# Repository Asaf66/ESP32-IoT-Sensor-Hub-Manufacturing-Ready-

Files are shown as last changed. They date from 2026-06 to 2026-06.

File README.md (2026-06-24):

# ESP32-C3 Multi-Sensor IoT & Data Logger
hardware system based on ESP32-C3 (RISC-V architecture) on a 4-layer PCB for noise immunity. 

The project includes sensors (environment, light, and sound), smart power and charging management (MCP73871), and a user interface.
The system supports local data storage via SD card and external flash memory via SPI connection, with Wi-Fi and BLE connectivity.

1) All-in-One Sensing Solution: Integrated temperature, humidity, light, and sound sensors, eliminating the need for multiple external modules.
2) Industrial-Grade Reliability: The 4-layer design ensures the device operates without interference in noisy industrial environments.
3) Seamless Power Integration: Built-in USB-C charging and battery management, meaning your product is portable and user-friendly from day one.
4) Rapid Manufacturing: Delivered with a full production package (Gerbers, BOM, Pick-and-Place), optimized to minimize assembly errors and part costs.

3D View
Sensores
User Interface
ESP32
Power
Front Back Layers
4 Layers

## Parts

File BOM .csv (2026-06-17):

Id | Designator | Footprint | Quantity | Designation | Supplier and ref
1 | R3,R4 | R_0805_2012Metric | 2 | 5K1
2 | LED2,LED5 | LEDC2012X120N | 2 | LTST-C170GKT
3 | R6 | R_0805_2012Metric | 1 | 20K
4 | C2,C8,C18,C14,C5,C21,C1,C10,C15,C13 | C_0805_2012Metric | 10 | 0.1u
5 | R12 | R_0805_2012Metric | 1 | 22K1
6 | C16 | C_0805_2012Metric | 1 | 0.1U
7 | LED4,LED6,LED1 | LEDC2012X120N | 3 | LTST-C170KRKT
8 | R5,R26,R28 | R_0805_2012Metric | 3 | 2K
9 | C22,C11,C19,C6 | C_0805_2012Metric | 4 | 1u
10 | LED3 | LEDC2012X120N | 1 | LTST-C170TBKT
11 | Q1 | TRANS_TEMT6000X01 | 1 | TEMT6000X01
12 | S2 | SW_USLPT2819DT2TR | 1 | RESET
13 | U6 | SOIC127P790X216-8N | 1 | W25Q32JVSSIQ
14 | R7,R14,R9,R8,R18,R10 | R_0805_2012Metric | 6 | 470
15 | R15,R22,R16,R20 | R_0805_2012Metric | 4 | 50
16 | U7 | SOT65P210X110-5N | 1 | MAX4466EXK
17 | R27,R29 | R_0805_2012Metric | 2 | 1M
18 | R24,R25 | R_0805_2012Metric | 2 | 4K7
19 | U5 | SOT-23-6 | 1 | USBLC6-2SC6
20 | TP3,TP5,TP4,TP2,TP1 | TestPoint_Pad_D1.0mm | 5 | TestPoint
21 | J4 | PinHeader_1x04_P2.54mm_Vertical | 1 | Conn_01x04_Pin
22 | U2 | PSON65P250X250X100-8N | 1 | BME280
23 | R23,R19,R33,R32,R34,R30,R2,R1 | R_0805_2012Metric | 8 | 10K
24 | J5 | PinHeader_1x05_P2.54mm_Vertical | 1 | Conn_01x05_Pin
25 | Q2,Q3 | SOT-23 | 2 | BC817
26 | U4 | SiliconLabs_QFN-20-1EP_3x3mm_P0.5mm_EP1.8x1.8mm | 1 | CP2102N-Axx-xQFN20
27 | F1 | FUSC3226X100N | 1 | 0ZCH0110AF2E
28 | S1 | SW_USLPT2819DT2TR | 1 | BOOT
29 | R11 | R_0805_2012Metric | 1 | 1K
30 | U3 | MODULE_ESP32-C3-WROOM-02-H4 | 1 | ESP32-C3-WROOM-02-H4
31 | U1 | QFN-20-1EP_4x4mm_P0.5mm_EP2.5x2.5mm | 1 | MCP73871-2CAI_ML
32 | C9 | T491A | 1 | 4.7u
33 | J2 | JST_B2B-PH-SM4-TB | 1 | B2B-PH-SM4-TB
34 | C17 | C_0805_2012Metric | 1 | 0.01U
35 | C20 | C_0805_2012Metric | 1 | 100p
36 | R13 | R_0805_2012Metric | 1 | 47K5
37 | C12,C3,C7,C4 | T491A | 4 | 10u
38 | MK1 | CUI_CMC-5042PF-AC | 1 | CMC-5042PF-AC
39 | R31 | R_0805_2012Metric | 1 | 100K
40 | J1 | BELFUSE_SS-52400-002 | 1 | SS-52400-002
41 | VR1 | VREG_LM1117MPX-3.3 | 1 | LM1117MPX-3.3
42 | J3 | AMPHENOL_GSD090012SEU | 1 | GSD090012SEU

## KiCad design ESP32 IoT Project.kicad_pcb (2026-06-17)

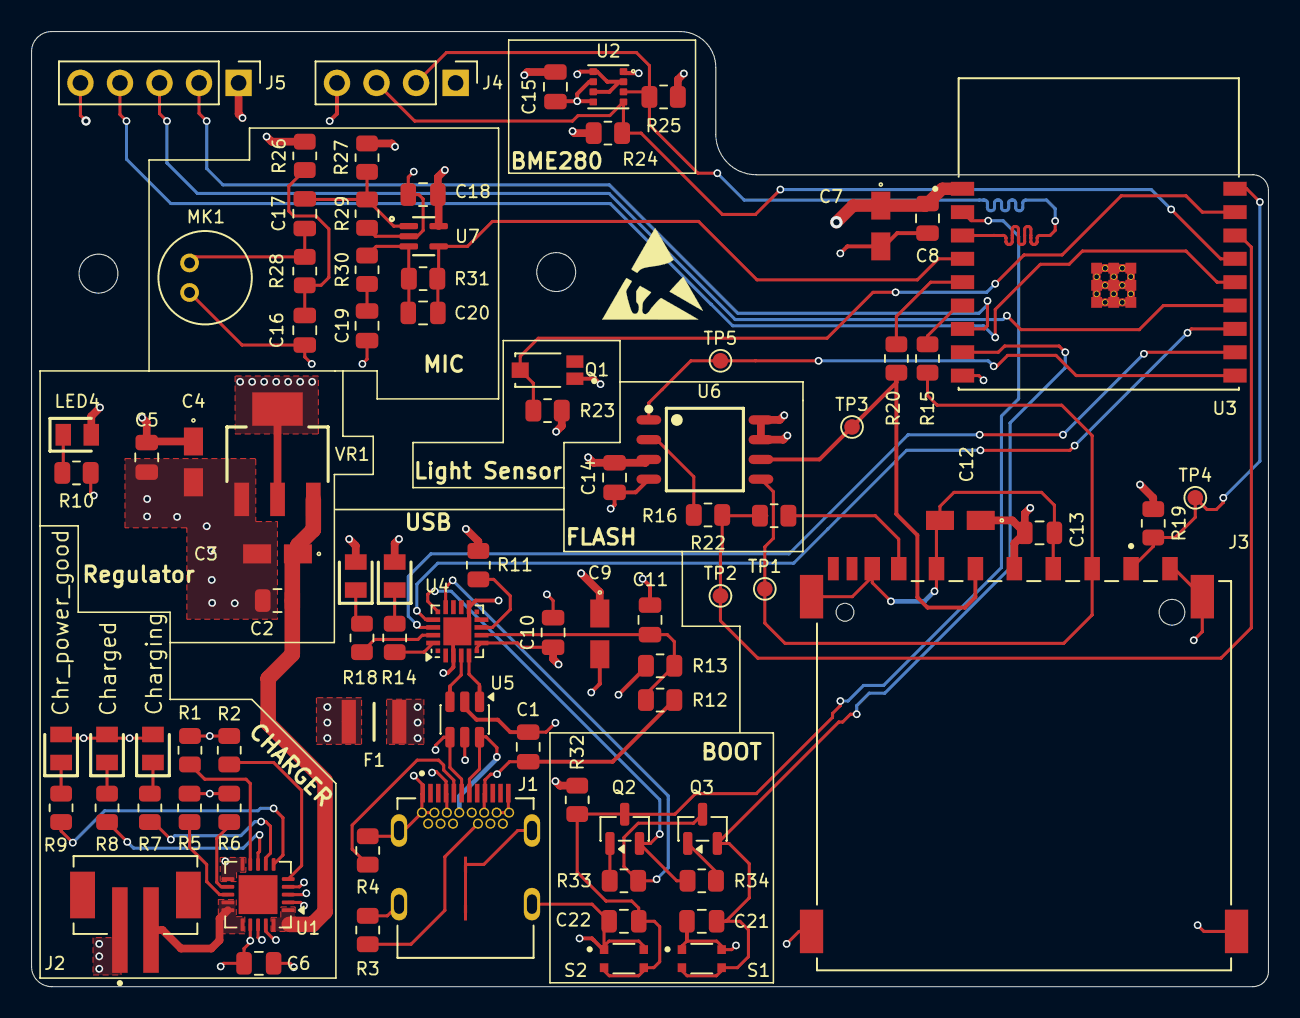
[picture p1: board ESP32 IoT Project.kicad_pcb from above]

Board: 4 copper layers, 79.5 x 61.4 mm, 85 parts (0 on the bottom side), 58 nets.

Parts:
C1, C2, C5, C8, C10, C13, C14, C15, C18, C21: 0.1u; C_0805_2012Metric
C3, C4, C7, C12: 10u; T491A
C6, C11, C19, C22: 1u; C_0805_2012Metric
C9: 4.7u; T491A
C16: 0.1U; C_0805_2012Metric
C17: 0.01U; C_0805_2012Metric
C20: 100p; C_0805_2012Metric
F1: 0ZCH0110AF2E; FUSC3226X100N
J1: SS-52400-002; BELFUSE_SS-52400-002
J2: B2B-PH-SM4-TB; JST_B2B-PH-SM4-TB
J3: GSD090012SEU; AMPHENOL_GSD090012SEU
J4: Conn_01x04_Pin; PinHeader_1x04_P2.54mm_Vertical
J5: Conn_01x05_Pin; PinHeader_1x05_P2.54mm_Vertical
LED1, LED4, LED6: LTST-C170KRKT; LEDC2012X120N
LED2, LED5: LTST-C170GKT; LEDC2012X120N
LED3: LTST-C170TBKT; LEDC2012X120N
MK1: CMC-5042PF-AC; CUI_CMC-5042PF-AC
Q1: TEMT6000X01; TRANS_TEMT6000X01
Q2, Q3: BC817; SOT-23
R1, R2, R19, R23, R30, R32, R33, R34: 10K; R_0805_2012Metric
R3, R4: 5K1; R_0805_2012Metric
R5, R26, R28: 2K; R_0805_2012Metric
R6: 20K; R_0805_2012Metric
R7, R8, R9, R10, R14, R18: 470; R_0805_2012Metric
R11: 1K; R_0805_2012Metric
R12: 22K1; R_0805_2012Metric
R13: 47K5; R_0805_2012Metric
R15, R16, R20, R22: 50; R_0805_2012Metric
R24, R25: 4K7; R_0805_2012Metric
R27, R29: 1M; R_0805_2012Metric
R31: 100K; R_0805_2012Metric
S1: BOOT; SW_USLPT2819DT2TR
S2: RESET; SW_USLPT2819DT2TR
TP1, TP2, TP3, TP4, TP5: TestPoint; TestPoint_Pad_D1.0mm
U1: MCP73871-2CAI_ML; QFN-20-1EP_4x4mm_P0.5mm_EP2.5x2.5mm
U2: BME280; PSON65P250X250X100-8N
U3: ESP32-C3-WROOM-02-H4; MODULE_ESP32-C3-WROOM-02-H4
U4: CP2102N-Axx-xQFN20; SiliconLabs_QFN-20-1EP_3x3mm_P0.5mm_EP1.8x1.8mm
U5: USBLC6-2SC6; SOT-23-6
U6: W25Q32JVSSIQ; SOIC127P790X216-8N
U7: MAX4466EXK; SOT65P210X110-5N
VR1: LM1117MPX-3.3; VREG_LM1117MPX-3.3

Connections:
+3.3V: C4.1, C5.1, C7.1, C8.2, C9.1, C10.2, C12.1, C13.2, C14.2, C15.2, C18.1, J3.4 (VDD1), J4.1, J5.1, LED4.2 (A), LED5.2 (A), LED6.2 (A), R11.2, R19.1, R23.2, R24.2, R25.2, R26.2, R27.2, R32.1, U2.2 (CSB), U2.6 (VDDIO), U2.8 (VDD), U3.1 (3V3), U4.6 (VDD), U4.7 (VREGIN), U6.3 (~WP(IO2)), U6.7 (~HOLD/~RESET(IO3)), U6.8 (VCC), U7.5 (VCC), VR1.2 (VOUT_2), VR1.4 (VOUT_4)
+5V: C2.1, C3.1, U1.1 (OUT), U1.20 (OUT), VR1.3 (VIN)
/+5V_USB: C6.1, F1.2, LED1.2 (A), LED2.2 (A), LED3.2 (A), U1.2 (VPCC), U1.4 (PROG2), U1.17 (CE), U1.18 (IN), U1.19 (IN)
/Charged: R8.2, U1.8 (STAT1/~LBO)
/Charging: R9.2, U1.6 (~PG)
/Charging_power_good: R7.2, U1.7 (STAT2)
/ESP32-C3-02/BOOT: C21.1, Q3.2 (E), S1.3, S1.4, U3.8 (IO9)
/ESP32-C3-02/CS: TP5.1, U3.10 (IO10), U6.1 (~CS)
/ESP32-C3-02/CS_SD: J3.1 (CD/DAT3), R19.2, TP4.1, U3.18 (IO0)
/ESP32-C3-02/DTR: Q3.3 (C), R33.2, U4.15 (~CTS)
/ESP32-C3-02/EN: C22.1, Q2.3 (C), R32.2, S2.3, S2.4, U3.2 (EN)
/ESP32-C3-02/GPIO8: J5.2, U3.7 (IO8)
/ESP32-C3-02/GPIO18: J5.3, U3.13 (IO18)
/ESP32-C3-02/GPIO19: J5.4, U3.14 (IO19)
/ESP32-C3-02/MIC_OUT: C20.1, R31.1, U3.4 (IO5), U7.4 (OUT)
/ESP32-C3-02/MISO_DO: R16.1, R22.2, TP2.1, U3.16 (IO2)
/ESP32-C3-02/MOSI_DI: J3.2 (CMD), R15.1, TP1.1, U6.5 (DI(IO0))
/ESP32-C3-02/PHOTO_C: Q1.3, R23.1, U3.17 (IO1)
/ESP32-C3-02/RTS: Q2.2 (E), R34.2, U4.16 (~RTS)
/ESP32-C3-02/RX: U3.12 (TXD), U4.17 (RXD)
/ESP32-C3-02/SCL: J4.3, R24.1, U2.4 (SCK), U3.15 (IO3)
/ESP32-C3-02/SCLK: J3.5 (CLK), R20.2, TP3.1, U6.6 (CLK)
/ESP32-C3-02/SDA: J4.2, R25.1, U2.3 (SDI), U3.3 (IO4)
/ESP32-C3-02/TX: U3.11 (RXD), U4.18 (TXD)
/ESP32-C3-02/USB_D+: U4.4 (D+), U5.3 (I/O2)
/ESP32-C3-02/USB_D-: U4.5 (D-), U5.1 (I/O1)
/PWD__LED: LED4.1 (K), R10.1
/USB_DN: J1.A7 (DN1), J1.B7 (DN2), U5.6 (I/O1)
/USB_DP: J1.A6 (DP1), J1.B6 (DP2), U5.4 (I/O2)
/VBAT: J2.2, U1.14 (VBAT), U1.15 (VBAT), U1.16 (VBAT_SENSE)
/VBUS: C1.1, F1.1, J1.A4 (VBUSA1), J1.A9 (VBUSA2), J1.B4 (VBUSB1), J1.B9 (VBUSB2), R12.2, U5.5 (VBUS)
GND: C1.2, C2.2, C3.2, C4.2, C5.2, C6.2, C7.2, C8.1, C9.2, C10.1, C11.2, C12.2, C13.1, C14.1, C15.1, C16.2, C18.2, C19.2, C21.2, C22.2, J1.A1 (GNDA1), J1.A12 (GNDA2), J1.B1 (GNDB1), J1.B12 (GNDB2), J1.G1 (GND/SHIELD), J1.G2 (GND/SHIELD), J1.G3 (GND/SHIELD), J1.G4 (GND/SHIELD), J1.S1 (GND/SHIELD), J1.S2 (GND/SHIELD), J1.S3 (GND/SHIELD), J1.S4 (GND/SHIELD), J2.1, J3.3 (VSS1), J3.6 (VSS2), J3.8 (DAT1), J3.9 (DAT2), J3.G1 (SHIELD_GND), J3.G2 (SHIELD_GND), J3.G3 (SHIELD_GND), J3.G4 (SHIELD_GND), J4.4, J5.5, MK1.GND, Q1.1, R1.2, R2.2, R3.1, R4.1, R5.1, R6.1, R10.2, R13.1, R29.1, S1.1, S1.2, S2.1, S2.2, U1.3 (SEL), U1.10 (VSS), U1.11 (VSS), U2.1 (GND), U2.5 (SDO), U2.7 (GND), U3.9 (GND), U3.19 (GND), U3.20 (GND), U3.21 (GND), U3.22 (GND), U3.23 (GND), U3.24 (GND), U3.25 (GND), U3.26 (GND), U3.27 (GND), U3.28 (GND), U3.29 (GND), U3.30 (GND), U3.31 (GND), U3.32 (GND), U3.33 (GND), U3.34 (GND), U3.35 (GND), U3.36 (GND), U3.37 (GND), U3.38 (GND), U3.39 (GND), U4.3 (GND), U4.12 (GND), U4.21 (GND), U5.2 (GND), U6.4 (GND), U7.2 (GND), VR1.1 (GND)
unnamed: C16.1, R26.1, R28.2
unnamed: C17.1, MK1.OUT, R28.1
unnamed: C19.1, R30.1
unnamed: J1.A5 (CC1), R4.2
unnamed: J1.B5 (CC2), R3.2
unnamed: J3.7 (DAT0), R16.2
unnamed: LED1.1 (K), R9.1
unnamed: LED2.1 (K), R8.1
unnamed: LED3.1 (K), R7.1
unnamed: LED5.1 (K), R14.1
unnamed: LED6.1 (K), R18.1
unnamed: Q2.1 (B), R33.1
unnamed: Q3.1 (B), R34.1
unnamed: R5.2, U1.13 (PROG1)
unnamed: R6.2, U1.12 (PROG3)
unnamed: R2.1, U1.5 (THERM)
unnamed: R1.1, U1.9 (~TE)
unnamed: R20.1, U3.5 (IO6)
unnamed: R15.2, U3.6 (IO7)
unnamed: C11.1, R12.1, R13.2, U4.8 (VBUS)
unnamed: R11.1, U4.9 (~RST)
unnamed: R18.2, U4.19 (~RXT/GPIO.3)
unnamed: R14.2, U4.20 (~TXT/GPIO.2)
unnamed: R22.1, U6.2 (DO(IO1))
unnamed: C17.2, R27.1, R29.2, U7.1 (IN+)
unnamed: C20.2, R30.2, R31.2, U7.3 (IN-)
